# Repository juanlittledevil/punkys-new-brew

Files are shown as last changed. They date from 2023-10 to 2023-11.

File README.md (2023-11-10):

## Punky's New Brew - Eurorack Drum Module

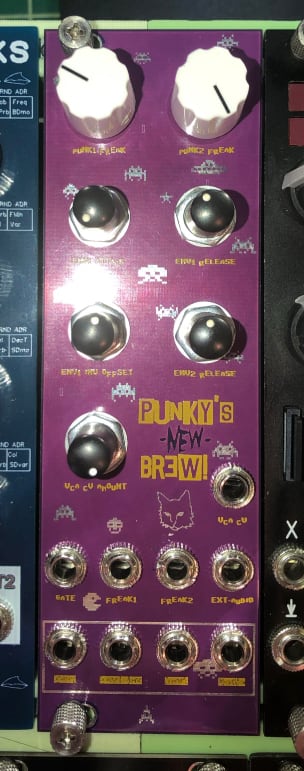
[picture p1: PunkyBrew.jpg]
Module Image


**Description:**
Punky's New Brew is a Eurorack drum-ish module made from the classic Atari Punk Console circuit. This DIY module produces percussive arcade-style sounds and is perfect for electronic music enthusiasts and synthesizer aficionados. This repository contains the KiCad project files, Gerber files, and other resources related to the construction of the module.

**YouTube Channel:** [Juan's YouTube Channel](https://www.youtube.com/channel/UC0b9VIyAkoUc2IhSYS2gNUg)

**Blog:** [Juan's Blog - Scruffy Cat Studios](scruffycatstudios.com)

For step-by-step instructions on how to build Punky's New Brew and to gain valuable insights into DIY electronics and Eurorack modules, be sure to check out the Scruffy Cat Studios YouTube channel and blog. Dive into the world of modular synthesis and start creating your own unique soundscapes with this punk!

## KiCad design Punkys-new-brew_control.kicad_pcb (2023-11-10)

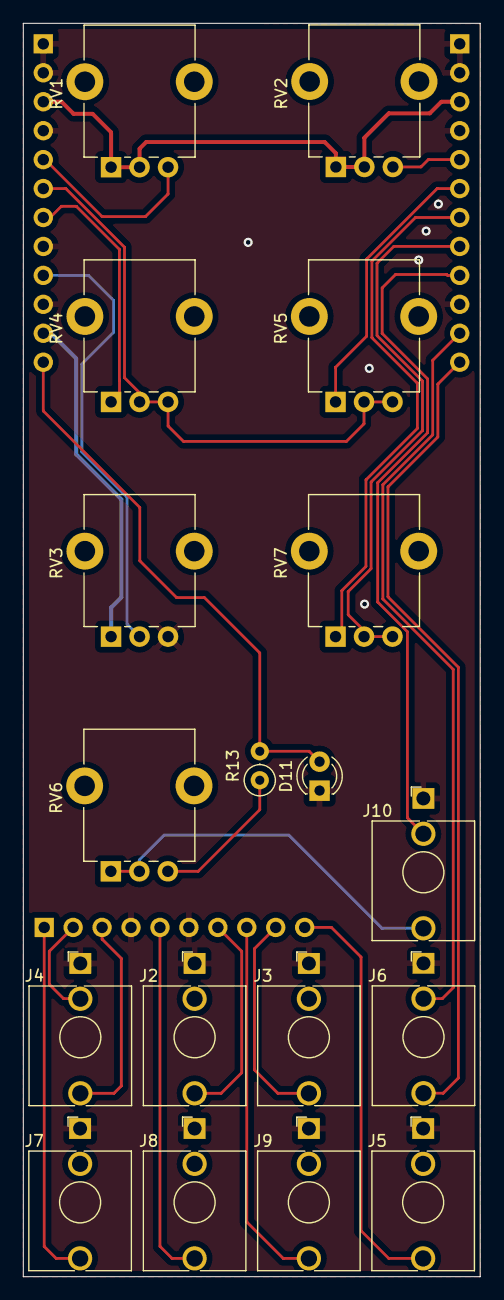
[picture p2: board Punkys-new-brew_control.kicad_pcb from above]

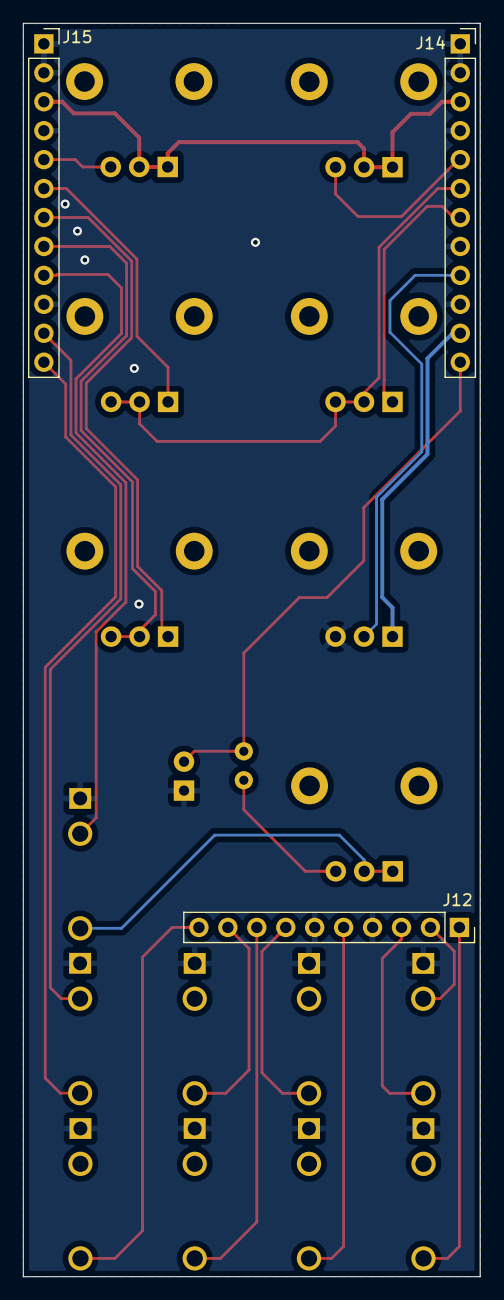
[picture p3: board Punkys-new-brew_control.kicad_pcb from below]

Board: 2 copper layers, 40.1 x 110.0 mm, 21 parts (3 on the bottom side), 25 nets.

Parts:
D11: LED; LED_D3.0mm
J2: CV1-In; Jack_3.5mm_QingPu_thonk-PJ398SM_Vertical_CircularHoles
J3: CV2-In; Jack_3.5mm_QingPu_thonk-PJ398SM_Vertical_CircularHoles
J4: Gate-In; Jack_3.5mm_QingPu_thonk-PJ398SM_Vertical_CircularHoles
J5: Audio-Out; Jack_3.5mm_QingPu_thonk-PJ398SM_Vertical_CircularHoles
J6: Ext-Audio; Jack_3.5mm_QingPu_thonk-PJ398SM_Vertical_CircularHoles
J7: ENV1; Jack_3.5mm_QingPu_thonk-PJ398SM_Vertical_CircularHoles
J8: INV_ENV1; Jack_3.5mm_QingPu_thonk-PJ398SM_Vertical_CircularHoles
J9: ENV2; Jack_3.5mm_QingPu_thonk-PJ398SM_Vertical_CircularHoles
J10: VCA-CV; Jack_3.5mm_QingPu_thonk-PJ398SM_Vertical_CircularHoles
J12: 1x10_control; PinSocket_1x10_P2.54mm_Vertical
J14: L_1x12_control; PinSocket_1x12_P2.54mm_Vertical
J15: R_1x12_control; PinSocket_1x12_P2.54mm_Vertical
R13: 1k; R_Axial_DIN0207_L6.3mm_D2.5mm_P2.54mm_Vertical
RV1, RV4, RV5: 1M; Potentiometer_Alpha_RD901F-40-00D_Single_Vertical_CircularH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
RV2, RV3, RV7: 500k; Potentiometer_Alpha_RD901F-40-00D_Single_Vertical_CircularH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
RV6: 100k; Potentiometer_Alpha_RD901F-40-00D_Single_Vertical_CircularH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

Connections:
5V_Ref_C: J4.3, J12.2
10V_REF_C: J14.11, RV3.1
+12V: J14.3, J15.3, RV1.1, RV1.2, RV2.1, RV2.2
APC_Out_C: J6.3, J15.11
Audio_Out_C: J5.2, J12.10
CV1-In_C: J2.2, J12.7
CV2-In_C: J3.2, J12.9
ENV1-Out_C: J7.2, J12.1
ENV1_C: J10.3, J15.9
ENV2_C: J9.2, J12.8
Env1_AR_C: J14.6, RV4.2, RV4.3, RV5.2, RV5.3
Env1_A_C: J14.7, RV4.1
Env1_R_C: J15.6, RV5.1
Env2_AR_C: J15.8, RV7.2, RV7.3
Env2_R_C: J15.7, RV7.1
Ext_In_C: J6.2, J15.12
Freq_1_C: J14.5, RV1.3
Freq_2_C: J15.5, RV2.3
GND: D11.1 (K), J2.1, J3.1, J4.1, J5.1, J6.1, J7.1, J8.1, J9.1, J10.1, J12.4, J12.6, J14.1, J14.2, J14.4, J14.8, J14.10, J15.1, J15.2, J15.4, J15.10, RV3.3
Gate_In_C: J4.2, J12.3
INV_ENV_C: J8.2, J12.5
INV_REF_C: J14.9, RV3.2
unnamed: J10.2, RV6.1, RV6.2
unnamed: R13.1, RV6.3
VCA_CV_C: D11.2 (A), J14.12, R13.2

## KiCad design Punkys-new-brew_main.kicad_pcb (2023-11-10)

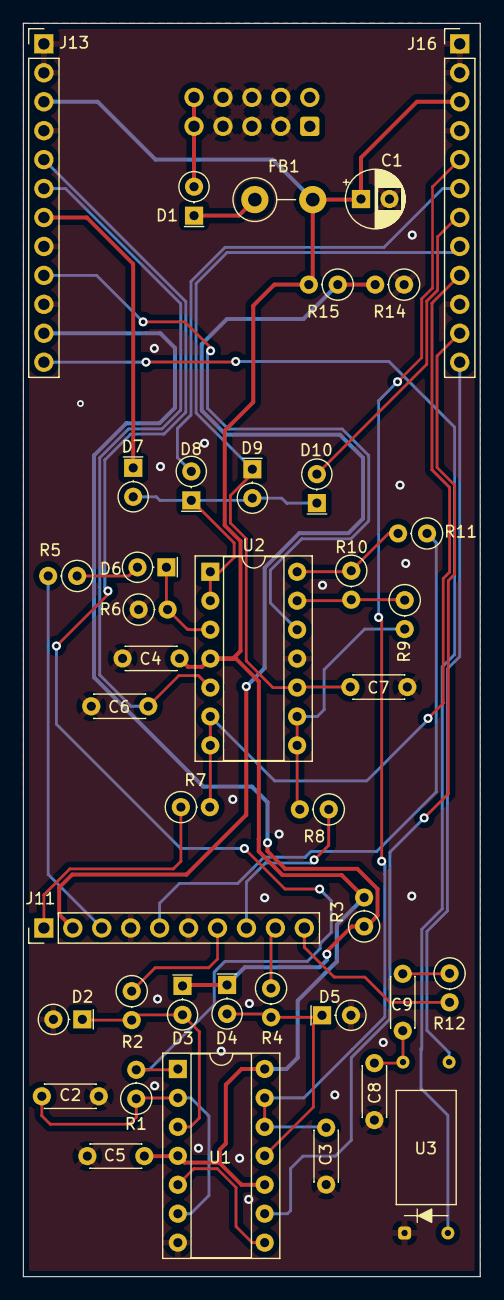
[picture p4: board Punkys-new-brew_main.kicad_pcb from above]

Board: 2 copper layers, 40.1 x 110.0 mm, 41 parts (1 on the bottom side), 37 nets.

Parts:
C1: C_Polarized_THL; CP_Radial_D5.0mm_P2.50mm
C2: 10nF; C_Disc_D4.3mm_W1.9mm_P5.00mm
C3: 47nF; C_Disc_D4.3mm_W1.9mm_P5.00mm
C4, C5: 100nF; C_Disc_D4.3mm_W1.9mm_P5.00mm
C6, C7, C9: 1uF; C_Disc_D4.3mm_W1.9mm_P5.00mm
C8: 2.2nF; C_Disc_D4.3mm_W1.9mm_P5.00mm
D1, D2, D3, D4, D5: Schottky; D_DO-35_SOD27_P2.54mm_Vertical_KathodeUp
D6, D7, D8, D9, D10: 1N4148; D_DO-35_SOD27_P2.54mm_Vertical_KathodeUp
FB1: FerriteBead; R_Axial_DIN0411_L9.9mm_D3.6mm_P5.08mm_Vertical
J1: +12v; IDC-Header_2x05_P2.54mm_Vertical
J11: 1x10_main; PinHeader_1x10_P2.54mm_Vertical
J13: L_1x12_main; PinHeader_1x12_P2.54mm_Vertical
J16: R_1x12_main; PinHeader_1x12_P2.54mm_Vertical
R1, R2, R4, R5, R7, R8, R11, R12: 1k; R_Axial_DIN0207_L6.3mm_D2.5mm_P2.54mm_Vertical
R3, R6, R9, R10, R14: 100k; R_Axial_DIN0207_L6.3mm_D2.5mm_P2.54mm_Vertical
R15: 140k; R_Axial_DIN0207_L6.3mm_D2.5mm_P2.54mm_Vertical
U1: LM556; DIP-14_W7.62mm_Socket
U2: TL074; DIP-14_W7.62mm_Socket
U3: VTL5C; Vactrol_DIY

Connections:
5V_Ref: J11.2, R14.2, R15.1
10V_REF: D3.1 (K), D4.1 (K), J13.11, R3.1
+12V: C1.1, C4.1, C5.2, FB1.2, J13.3, J16.3, R3.2, R15.2, U1.4 (R), U1.10 (R), U1.14 (VCC), U2.4 (V+)
APC_Out: J16.11, U1.9 (Q)
Audio_Out: J11.10, R12.2
CV1: D2.1 (K), D3.2 (A), R2.2, U1.3 (CV)
CV1-In: J11.7, R2.1
CV2: D4.2 (A), D5.1 (K), R4.2, U1.11 (CV)
CV2-In: J11.9, R4.1
ENV1: J16.9, R7.2, U2.6 (-), U2.7
ENV1-Out: J11.1, R7.1
ENV2: J11.8, R8.1
Env1_A: D7.1 (K), J13.7
Env1_AR: C6.1, J13.6, U2.5 (+)
Env1_R: D8.2 (A), J16.6
Env2_AR: C7.1, D9.1 (K), J16.8, U2.10 (+)
Env2_R: D10.2 (A), J16.7
Ext_In: J16.12, U3.4
Freq_1: J13.5, R1.2, U1.1 (DIS)
Freq_2: C3.1, J16.5, U1.12 (THR), U1.13 (DIS)
GND: C1.2, C2.2, C3.2, C4.2, C5.1, C6.2, C7.2, C8.2, D2.2 (A), D5.2 (A), J1.3 (GND), J1.4 (GND), J1.5 (GND), J1.6 (GND), J1.7 (GND), J1.8 (GND), J11.4, J11.6, J13.1, J13.2, J13.4, J13.8, J13.10, J16.1, J16.2, J16.4, J16.10, R6.1, R14.1, U1.7 (GND), U2.11 (V-), U3.1 (-)
Gate_In: J11.3, R5.2
INV_ENV: J11.5, R11.1
INV_REF: J13.9, U2.12 (+)
unnamed: C8.1, C9.1, U3.3
unnamed: C9.2, R12.1
unnamed: D1.2 (A), J1.9 (12v), J1.10 (12v)
unnamed: D1.1 (K), FB1.1
unnamed: D6.2 (A), R5.1
unnamed: D6.1 (K), R6.2, U2.3 (+)
unnamed: D7.2 (A), D8.1 (K), D9.2 (A), D10.1 (K), U2.1, U2.2 (-)
unnamed: R10.1, R11.2, U2.14
unnamed: U1.5 (Q), U1.8 (TR)
unnamed: C2.1, R1.1, U1.2 (THR), U1.6 (TR)
unnamed: R8.2, R9.2, U2.8, U2.9 (-)
unnamed: R9.1, R10.2, U2.13 (-)
VCA_CV: J13.12, U3.2 (+)

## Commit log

2023-11-10 fixed some values to better suit my liking. re-routed the invert to env2 instead, it works better me finks.
    [Punkys-new-brew.csv, Punkys-new-brew.kicad_sch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]
2023-11-13 update panel gerbers
    [Punkys-new-brew_panel-B_Cu.gbr, Punkys-new-brew_panel-B_Mask.gbr, Punkys-new-brew_panel-B_Paste.gbr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]
